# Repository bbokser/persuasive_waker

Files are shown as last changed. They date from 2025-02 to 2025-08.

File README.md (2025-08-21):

# persuasive_waker

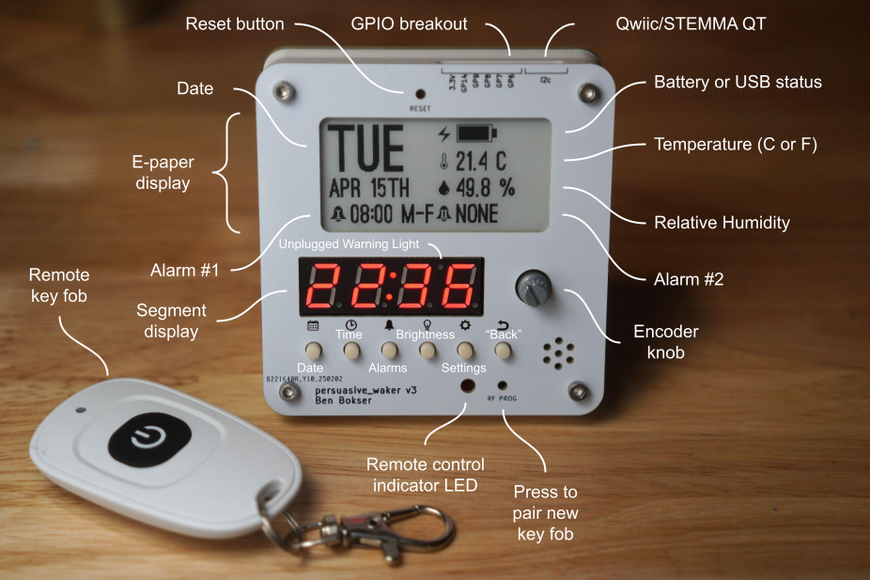
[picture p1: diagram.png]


Persuasive Waker is an open source hardware alarm clock that can't be snoozed or turned off. The alarm is deactivated via a remote key fob, which should be placed as far from the user's bed as possible. E.g. in the bathroom.

The KiCad design files are located in the [`hw`](hw) folder.

The STEP assembly is located [here](hw/step/).

If you just want STLs for printing, they're [here](hw/stl).

## BoM
| Item | QTY| Source |
| ---| ---|--|
| Case | 1  | 3D Print |
| Screen Holder | 1  | 3D Print |
| Spacer | 2  | 3D Print |
| M2.5x0.45-12-SHCS-SS304 | 4  | |
| M2.5x0.45-6-SHCS-SS304 | 4  | |
| M2.5x0.45-4-FHS-SS304 | 2 | |
| PRESSNUT-M2.5x0.45-SS304 | 2 | [Mouser](https://mou.sr/3FToM2v)|
| Battery Holder | 1 | [Mouser](https://mou.sr/4lddciV) |
| THRIN-M2.5X0.45-HS-PL-4L3.5D-BR | 8 | [Amazon](https://www.amazon.com/dp/B0DGPL6RWT)|
| E-Paper Display | 1 | [AliExpress](https://www.aliexpress.us/item/2251832627460771.html)|
| Key Fob | 1 | [AliExpress](https://www.aliexpress.us/item/2251832657961546.html) |
| Alarm PCB | 1 | Custom PCBA Order |
| Front Plate | 1 | Custom PCB Order  |
| Rear Plate | 1 | Custom PCB Order  |

## Mechanical Build
1. Print the case, screen holder, and two spacers.
2. Install the heat-set inserts in the case (x8).
3. Insert the PCB from the front.
4. Plug the E-paper display into the FPC connector.
5. Put the screen holder and spacers into position and then fold the display down onto it. Make sure the display is properly nestled in.
6. Holding the display down, put the front cover on.
7. Screw the front cover on with the M2.5x12 screws.
8. Using an arbor press, press the press-fit nuts into the rear cover.
9. Screw the battery holder onto the rear cover using the flat head screws and loctite. Insert AA batteries.
10. Plug the battery holder into the power connector on the back of the PCB.
11. Screw the rear cover on using the M2.5x6 screws.

## Firmware Setup
1. Install CircuitPython on your Pico by following [this](https://learn.adafruit.com/getting-started-with-raspberry-pi-pico-circuitpython/circuitpython) guide.
The last version tested with this device is [9.2.6.](https://adafruit-circuit-python.s3.amazonaws.com/bin/raspberry_pi_pico/en_US/adafruit-circuitpython-raspberry_pi_pico-en_US-9.2.6.uf2)

2. Install [circup](https://learn.adafruit.com/keep-your-circuitpython-libraries-on-devices-up-to-date-with-circup/prepare) on your computer.

3. Run the following commands to install all necessary libraries.

    ```
    circup bundle-add adafruit/circuitpython-fonts
    circup install adafruit_sht4x adafruit_ssd1680 adafruit_display_text adafruit_ds3231 adafruit_datetime adafruit_display_shapes font_ostrich_sans_black_24 font_ostrich_sans_black_60
    ```
4. Delete `code.py` from the Pico's storage.

5. Clone this repo onto your computer and copy+paste everything in the `src` folder to the Pico's storage.

6. The alarm clock should be functioning now.

## User Manual
See [here](user_manual.md).

### Upgrading from v3.0 to v3.1
1. Replace the old `src` files with the new ones on the `v3.1` branch.
2. Install [circup](https://learn.adafruit.com/keep-your-circuitpython-libraries-on-devices-up-to-date-with-circup/prepare) and run the following.
    ```
    circup bundle-add adafruit/circuitpython-fonts
    circup uninstall font_ostrich_sans_black_30 font_ostrich_sans_black_72
    circup install font_ostrich_sans_black_24 font_ostrich_sans_black_60
    circup update
    ```
    
    Alternatively, you can download the [requirements.txt](requirements.txt) and run the following:
    
    ```
    circup install -r /path/to/requirements.txt
    ```

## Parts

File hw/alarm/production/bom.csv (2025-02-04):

Designator | Footprint | Quantity | Value | LCSC Part #
C1, C18, C3, C6 | 603 | 4 | 4.7uF | C8032
C10, C11, C12, C13, C14, C15, C16, C17, C2, C4, C5, C7, C8, C9 | 603 | 14 | 1uF | C105524
D1, D2, D3, D4 | D_SOD-123 | 4 | MBR0530 | C77336
IC1 | SHT40BD1BR2 | 1 | SHT40-BD1B-R2 | C7461849
IC2 | MAX31328NELB | 1 | MAX31328NELB+ | C3303818
IC3 | PEC11S929KS0015 | 1 | PEC11S-929K-S0015 | C5362681
J1 | FFC2B3524T | 1 | FFC2B35-24-T | C5641278
J3 | M207920642R | 1 | M20-7920642R | C19188561
J4 | SM04BSRSSTBLFSNP | 1 | SM04B-SRSS-TB_LF__SN__P_ | C160404
L1 | INDM3225X240N | 1 | 68 uH | C1499398
LED1 | WP424IDT | 1 | WP424IDT | C5878956
LS1 | CSSI4B20SMTTR | 1 | CSS-I4B20-SMT-TR | C7116026
Q1 | SOT65P210X110-3N | 1 | Si1308EDL-T1-GE3 | C469327
Q2, Q3 | SOT96P240X115-3N | 2 | DMG2305UX-7 | C150470
Q4 | 2SC5585TL | 1 | 2SC5585TL | C337983
R1, R10, R11, R3, R4, R5, R7, R8, R9 | 603 | 9 | 10kΩ | C15401
R12 | 603 | 1 | 14kΩ | C137795
R13 | 603 | 1 | 1kΩ | C103198
R14 | 603 | 1 | 47Ω | C1211
R15, R16 | 603 | 2 | 130Ω | C22796
R2 | 603 | 1 | 0.47Ω | C23411
R6 | 603 | 1 | 180Ω | C100819
S1, S2 | RKB2SJK250SMTRLFS | 2 | RKB2SJK250SMTR_LFS | C2927789
S3, S4, S5, S7, S8, S9 | TL3301BF260QJ | 6 | TL3301BF260QJ | C2886846
U3 | QSOP-24_3.9x8.7mm_P0.635mm | 1 | AS1115-BSST | C2649434
U4 | TDCG1060M_VIS | 1 | TDCR1060M | C7067210

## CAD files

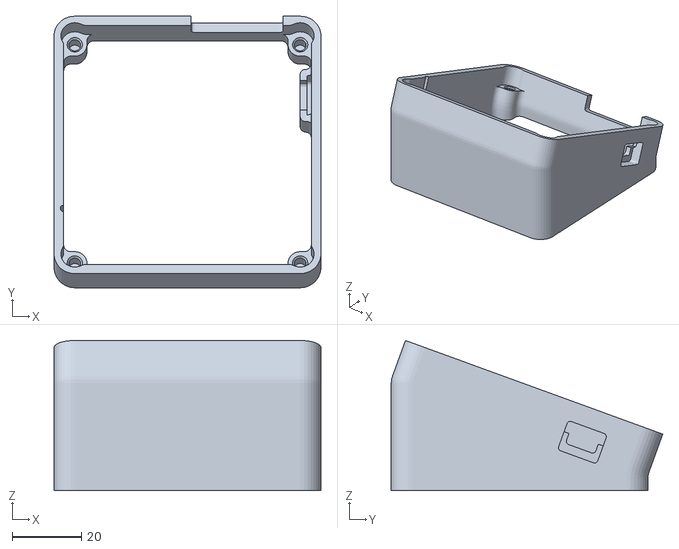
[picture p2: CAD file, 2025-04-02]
hw/stl/CASE V3.STL
77.0 x 78.3 x 43.3

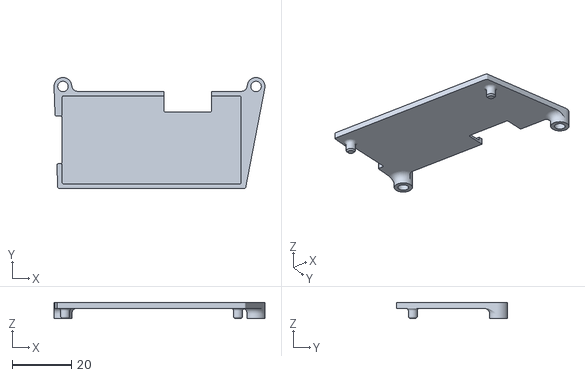
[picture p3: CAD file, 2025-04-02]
hw/stl/SCREEN HOLDER.STL
71.0 x 37.3 x 5.50

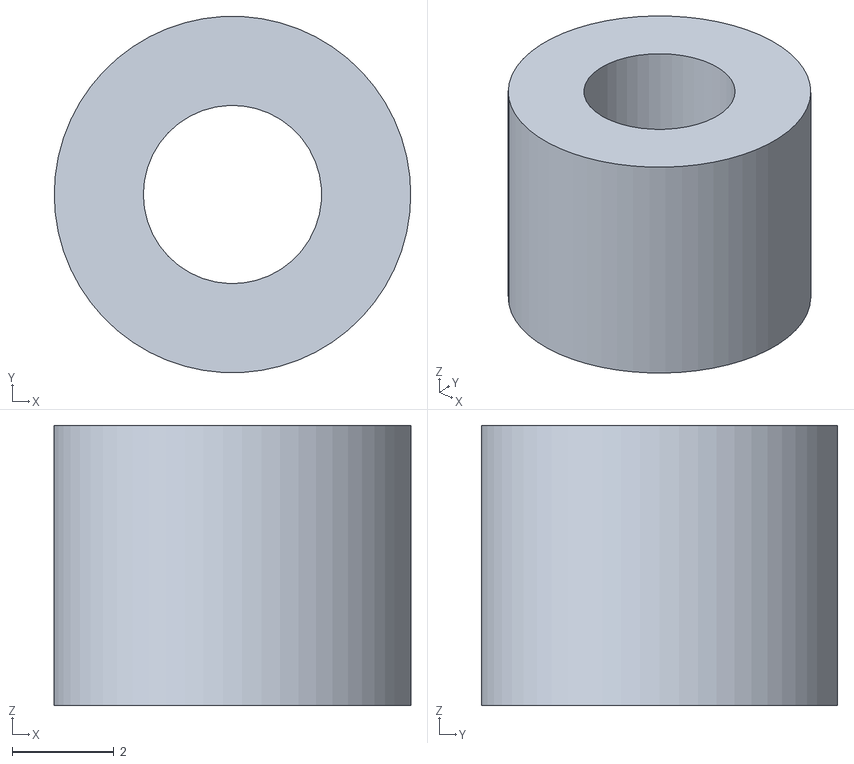
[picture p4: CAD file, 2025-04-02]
hw/stl/SPACER.STL
7.00 x 6.99 x 5.50

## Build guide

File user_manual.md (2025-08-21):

# persuasive_waker: User Manual



## Getting Started
1. Install two AA batteries in the battery compartment.
2. Using the provided screws, screw the back plate onto the case with the batteries on the inner side.
3. Connect the clock to a power source via the USB cable. 
4. Holding down the key fob button, press the date button and select the year by rotating the knob. Press the knob inwards to hit "enter".
5. You will now be asked to enter in the month, followed by the day of the month.
6. Press the time button to set the time of day in a similar manner. 

You can only enter the date, time, and alarm setting mode while simultaneously holding down the key fob button. Otherwise, the device will simply emit an "error" sound effect. This feature is meant to prevent your future self from simply changing the alarm setting (or date/time) a minute before the alarm goes off to avoid getting out of bed.

> [!WARNING]  
> Do not rely on the batteries for power. They will run out fairly quickly. The batteries are for backup power--to prevent pulling the plug from stopping the alarm.

> [!WARNING]  
> Do not attempt to use non-alkaline batteries.

## Using the Alarm
- After setting the alarm hour and time, the display will switch to showing seven flashing lines, which represent the days of the week. You can then choose which days the alarm is set for. The order starts with Monday and ends with Sunday.
- If you wish to cancel your alarm, press the alarm button and then press the "back" button.
- You can enter the second alarm setting mode by pressing the alarm button twice in a row.
- Press the button on the key fob to deactivate the alarm when it sounds. 

I recommend keeping the key fob far away from your bed, probably in the bathroom. But not so far that it's out of range. You should test it before you put it to use--the range will vary depending on your walls.

## Additional Functionalities
### Brightness
- The brightness button will allow you to set the screen brightness.
### Temperature Units
- Hit the option button once to choose your preferred units for temperature.
### Alarm Pitch
- Hit the option button twice to go into the menu for setting the alarm's pitch.
### 24-Hour vs 12-Hour Option
- Hit the option button thrice to go into the menu for selecting between 12-hour mode and 24-hour mode.

## The RESET Button
Try the RESET button if the device seems to be stuck in a bad state. But please notify me if this happens. Or create an [issue](https://github.com/bbokser/persuasive_waker/issues).

> [!NOTE]  
> If you press the RESET button, the E-paper screen will temporarily stop showing the alarm time even though the alarm is still enabled. This is a known issue due to the alarm time being stored in the RTC (clock) chip, not the microprocessor. Transfering this data from the RTC to the microprocessor may require modifications to the [`adafruit_ds3231`](https://docs.circuitpython.org/projects/ds3231/en/latest/api.html#adafruit_ds3231.DS3231.alarm1) library, which I haven't gotten around to. You will have to set the alarm again to make it show.

## Pairing With a New Key Fob
The remote switch receiver is an [RX480E](https://qiachip.com/products/2x-learning-code-receiver-module-for-rf-433mhz-rx-480-e-remote-control-arduino-chip-28131mm-pcb). Use the following instructions to pair a new key fob with your alarm clock (This won't be necessary straight out of the box).

1. Delete existing data by pressing the RF PROG button 8 times. You should see the LED flash 7 times.
2. Learn the new remote by pressing the RF PROG button once. (Note that if you instead press the button twice or thrice in a row, you'll go into other modes, such as toggle mode, which aren't useful for this device. See the link above for more details).
3. The LED should light up, at which point you should press the button on the key fob.
4. You should see the LED flash 3 times. From now on the LED should light up whenever you hit the remote button.

## Updating or Modifying the Software
Modification is as simple as connecting the device to your computer via USB and modifying the .py files.

You can learn more about working with RasPi Pico with CircuitPython [here](https://learn.adafruit.com/getting-started-with-raspberry-pi-pico-circuitpython/circuitpython).

You may encounter a "read-only" error while attempting to save changes. In my experience, this can be fixed by resetting the device.

To update to the latest version, you should follow the firmware setup instructions in the README.

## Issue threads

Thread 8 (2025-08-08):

Qwiic pinout is backward

bbokser, 2025-08-08:
Footprint/schematic is reversed, so the i2c breakout doesn't work out of the box.

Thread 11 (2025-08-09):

RF PROG button doesn't work with legitimate RX480Es

bbokser, 2025-08-09:
Schematic wiring for the RF PROG button is incorrect and needs to be redone. This wasn't caught because it worked with the bootleg versions of the RF board. Should be a pretty simple fix though.

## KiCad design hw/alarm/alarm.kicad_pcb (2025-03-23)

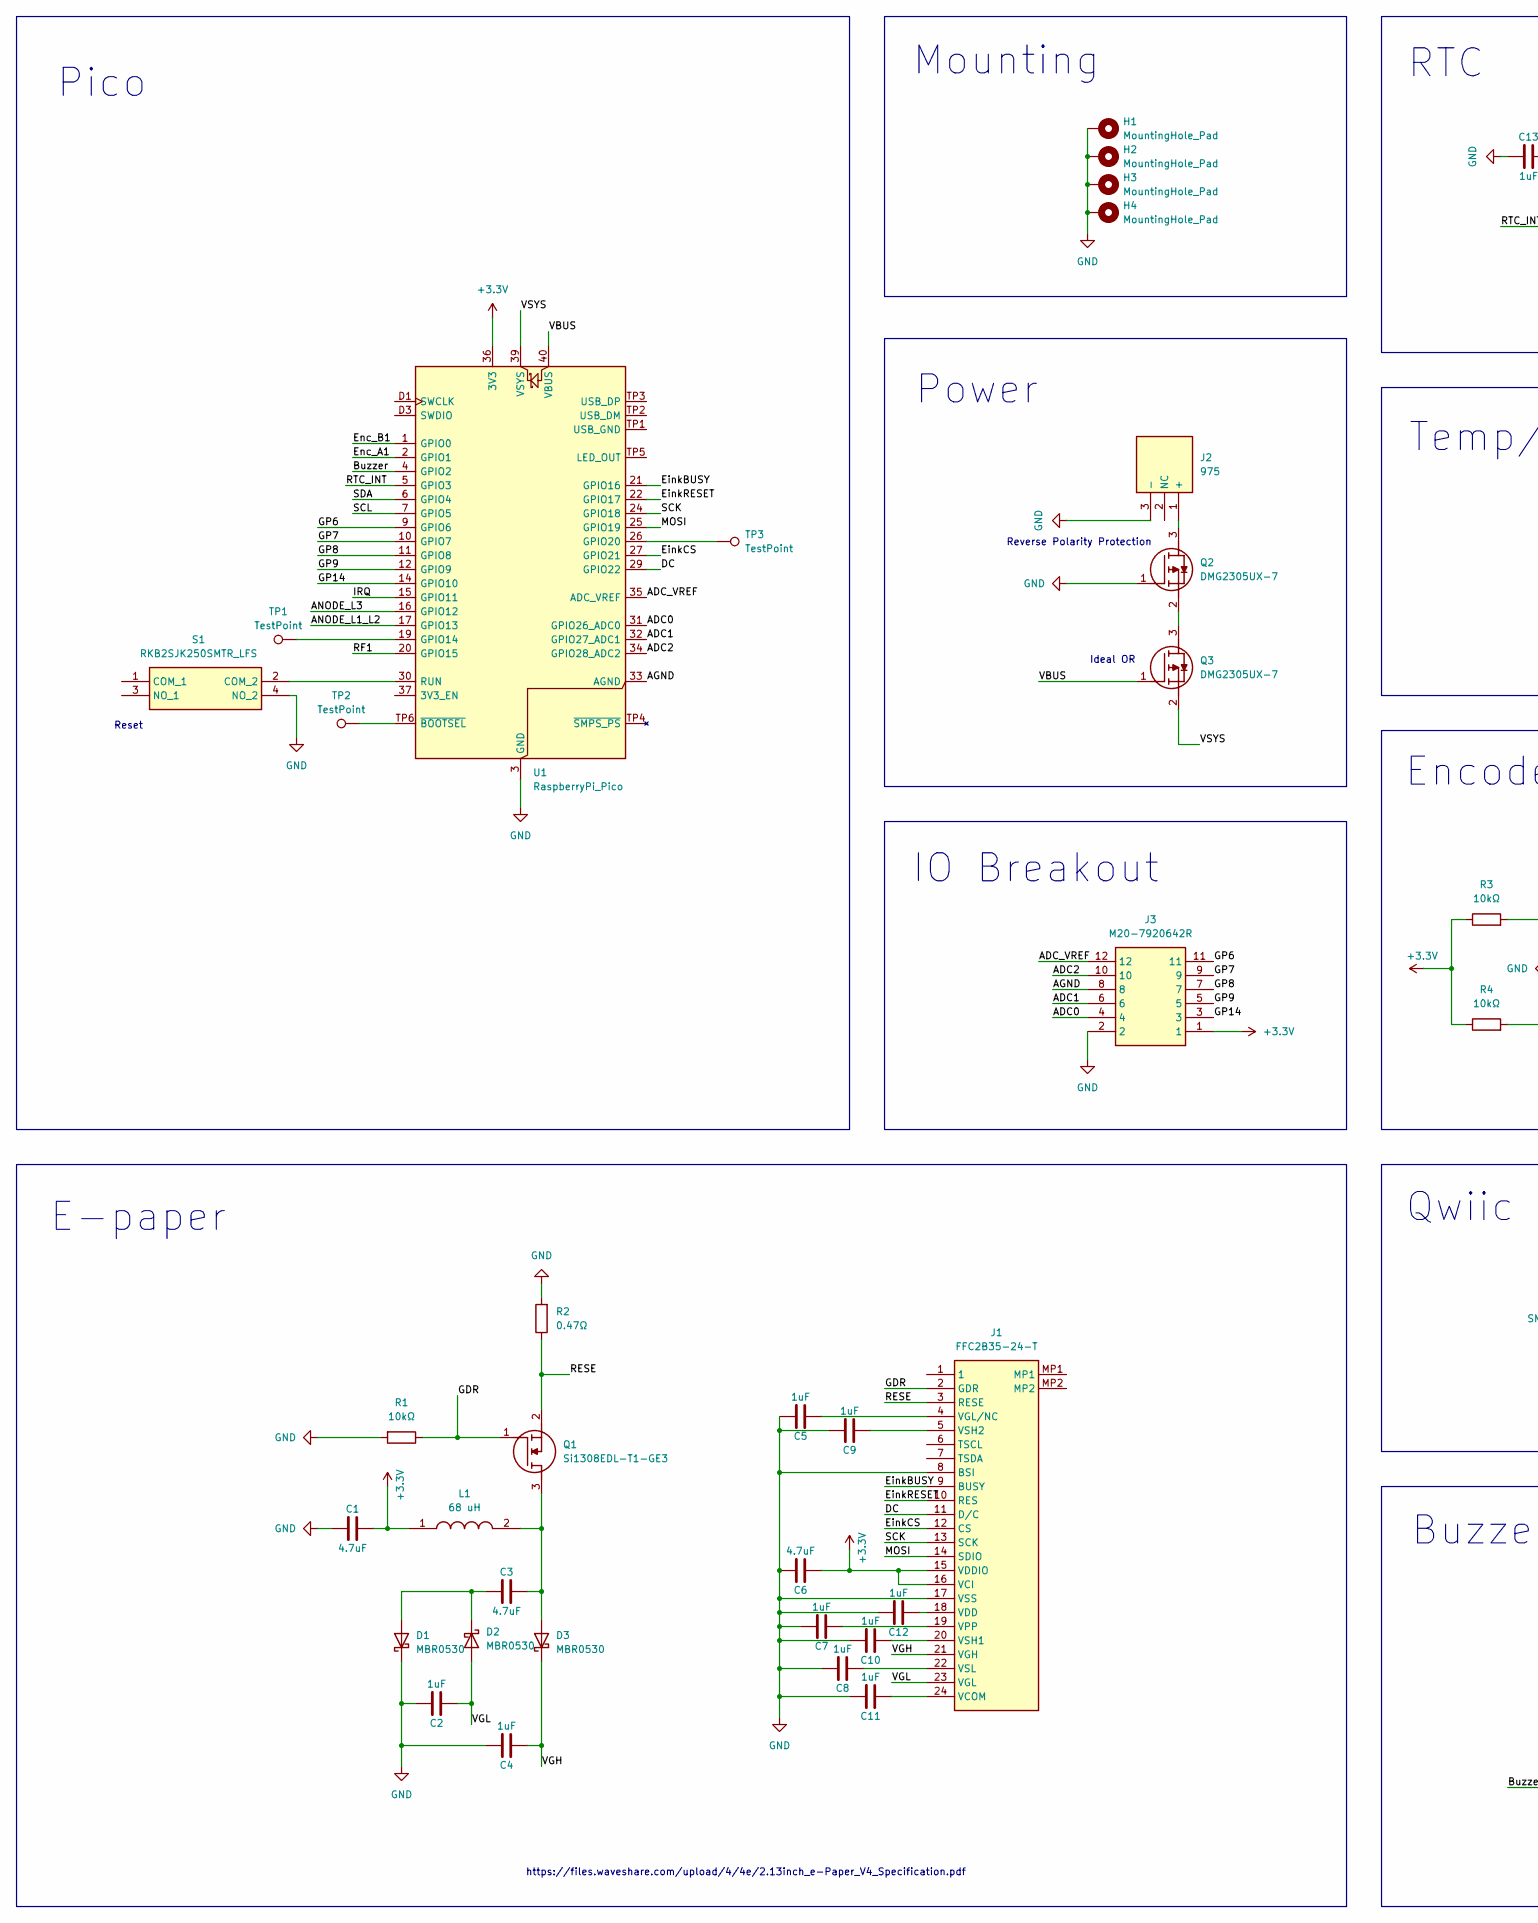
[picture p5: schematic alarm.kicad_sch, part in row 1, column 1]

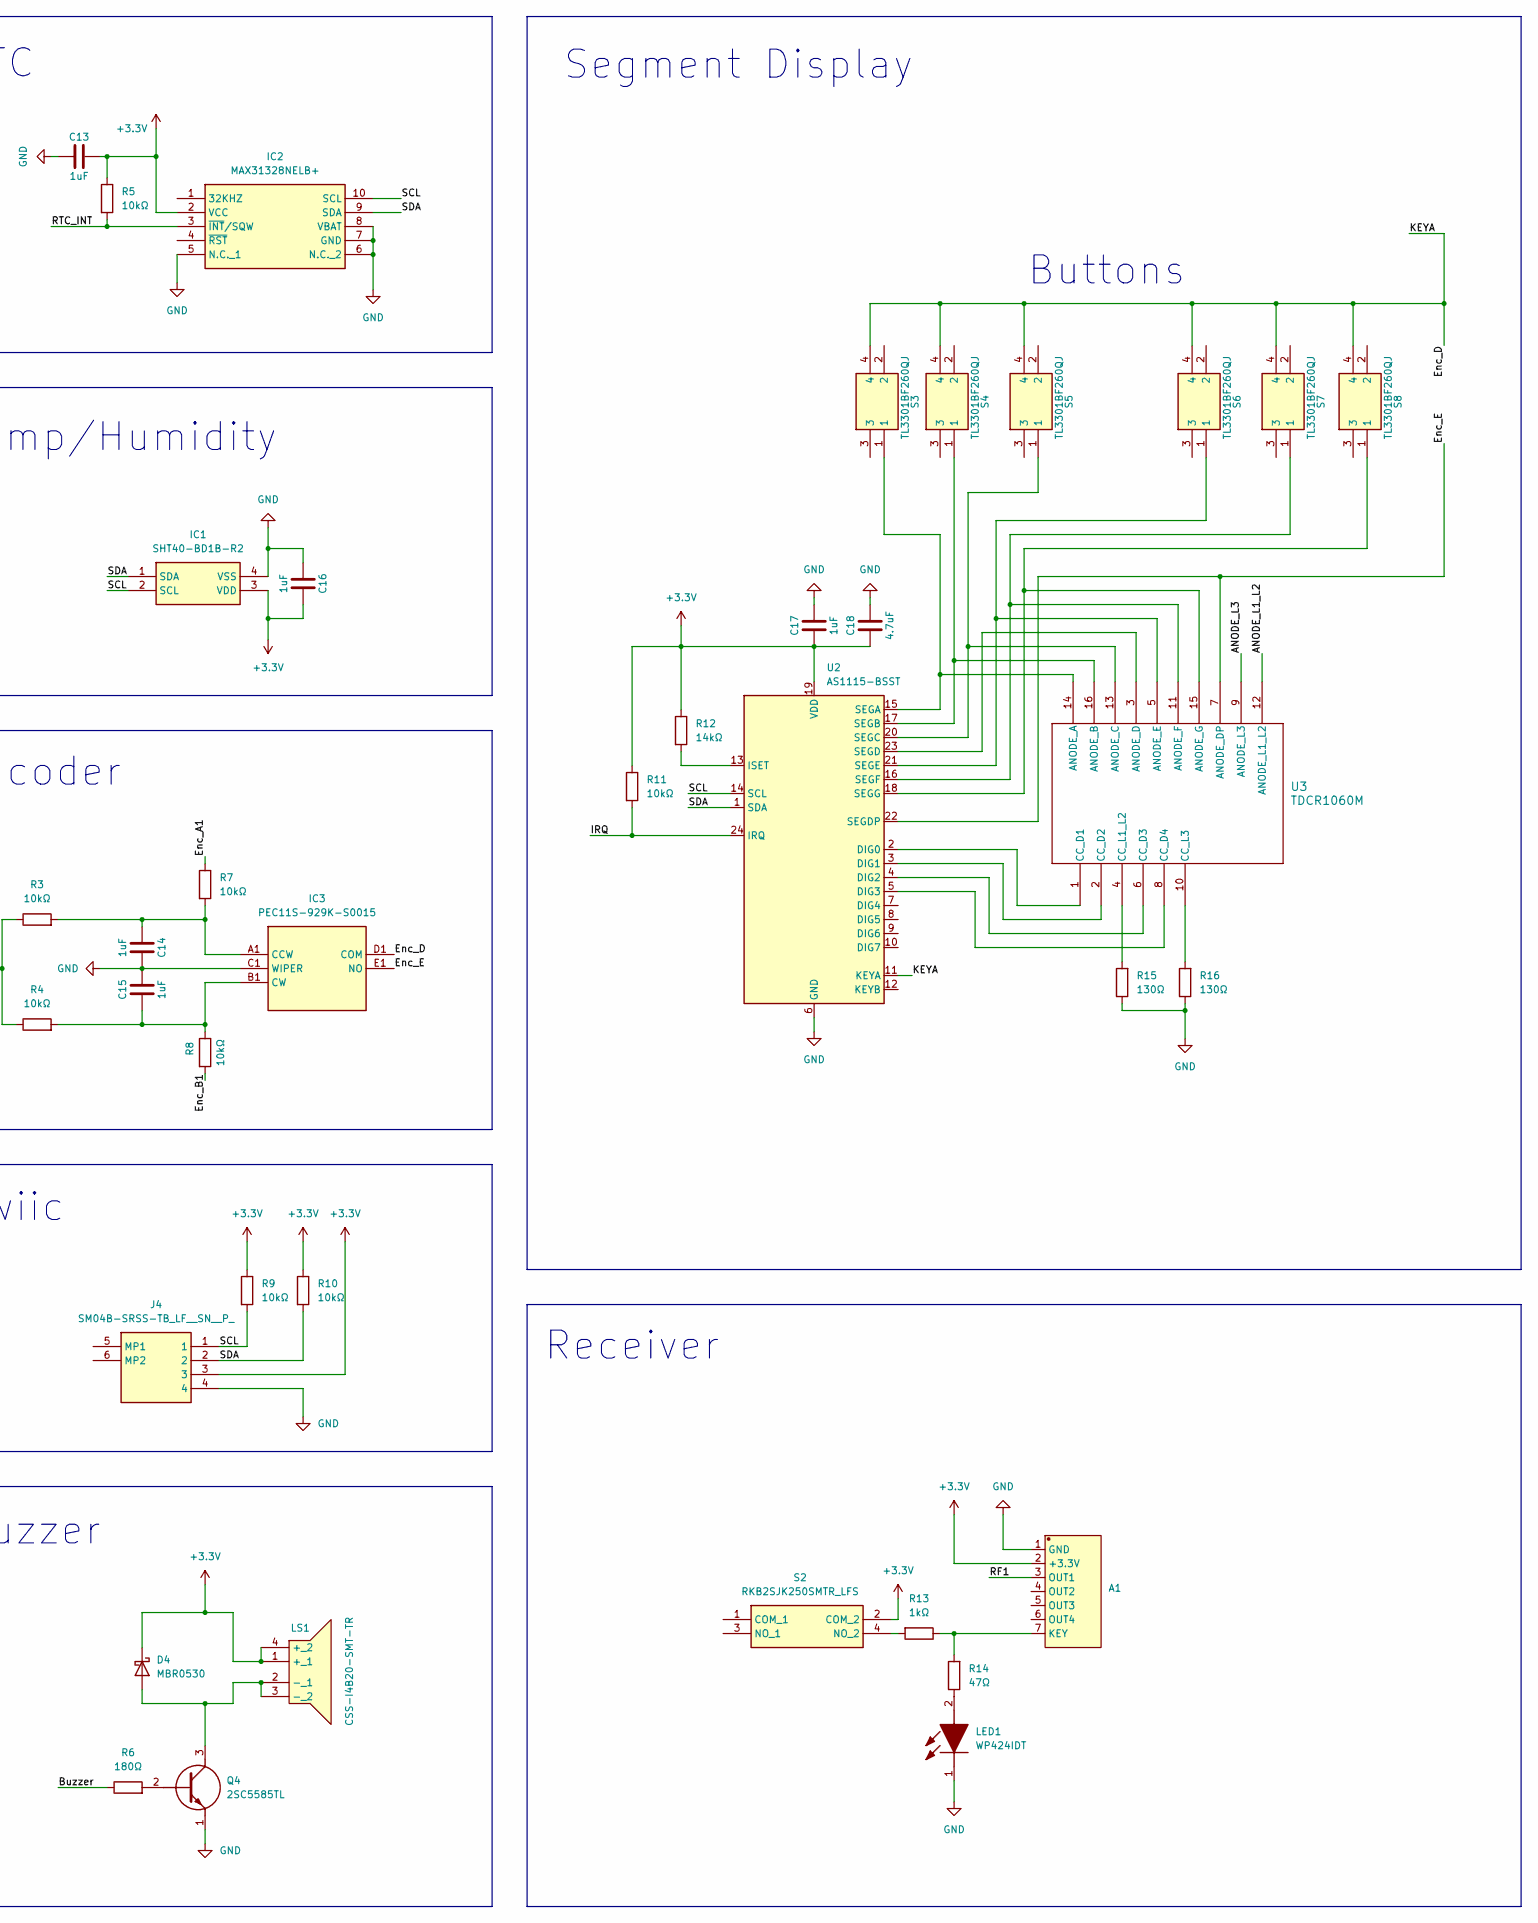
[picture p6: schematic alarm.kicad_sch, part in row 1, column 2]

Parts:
A1: RX480E
C1, C3, C6, C18: 4.7uF; C_0603_1608Metric; LCSC Part # C8032
C2, C4, C5, C7, C8, C9, C10, C11, C12, C13, C14, C15, C16, C17: 1uF; C_0603_1608Metric; LCSC Part # C105524
D1, D2, D3, D4: MBR0530; D_SOD-123; LCSC Part # C77336
H1, H2, H3, H4: MountingHole_Pad; MountingHole_2.7mm_M2.5_DIN965_Pad
IC1: SHT40-BD1B-R2; SHT40BD1BR2; Mouser Part Number 403-SHT40-BD1B-R2
IC2: MAX31328NELB+; MAX31328NELB; Mouser Part Number 700-MAX31328NELB+
IC3: PEC11S-929K-S0015; PEC11S929KS0015; Mouser Part Number 652-PEC11S929K-S0015
J1: FFC2B35-24-T; FFC2B3524T; Mouser Part Number 640-FFC2B35-24-T
J2: 975; Mouser Part Number 534-975
J3: M20-7920642R; M207920642R; Manufacturer_Part_Number M20-7920642R; LCSC Part # C19188561
J4: SM04B-SRSS-TB_LF__SN__P_; SM04BSRSSTBLFSNP; Mouser Part Number 306-SM04BSRSSTBLFSNP
L1: 68 uH; INDM3225X240N; Mouser Part Number 652-CM322522-680KL
LED1: WP424IDT; Mouser Part Number 604-WP424IDT
LS1: CSS-I4B20-SMT-TR; CSSI4B20SMTTR; Mouser Part Number 490-CSS-I4B20-SMT-TR
Q1: Si1308EDL-T1-GE3; SOT65P210X110-3N; Mouser Part Number 78-SI1308EDL-T1-GE3
Q2, Q3: DMG2305UX-7; SOT96P240X115-3N; Mouser Part Number 621-DMG2305UX-7
Q4: 2SC5585TL; Mouser Part Number 755-2SC5585TL
R1, R3, R4, R5, R7, R8, R9, R10, R11: 10kΩ; R_0603_1608Metric_Pad0.98x0.95mm_HandSolder; LCSC Part # C15401
R2: 0.47Ω; R_0603_1608Metric_Pad0.98x0.95mm_HandSolder; LCSC Part # C23411
R6: 180Ω; R_0603_1608Metric_Pad0.98x0.95mm_HandSolder; LCSC Part # C100819
R12: 14kΩ; R_0603_1608Metric_Pad0.98x0.95mm_HandSolder; LCSC Part # C137795
R13: 1kΩ; R_0603_1608Metric_Pad0.98x0.95mm_HandSolder; LCSC Part # C103198
R14: 47Ω; R_0603_1608Metric_Pad0.98x0.95mm_HandSolder; LCSC Part # C1211
R15, R16: 130Ω; R_0603_1608Metric_Pad0.98x0.95mm_HandSolder; LCSC Part # C22796
S1, S2: RKB2SJK250SMTR_LFS; RKB2SJK250SMTRLFS; Mouser Part Number 611-RKB2SJK250SMTRLF
S3, S4, S5, S6, S7, S8: TL3301BF260QJ; Mouser Part Number 612-TL3301BF260QJ
TP1, TP2, TP3: TestPoint; TestPoint_Pad_1.5x1.5mm
U1: RaspberryPi_Pico; RaspberryPi_Pico_Original_SMD
U2: AS1115-BSST; QSOP-24_3.9x8.7mm_P0.635mm; LCSC Part # C2649434
U3: TDCR1060M; TDCG1060M_VIS; LCSC Part # C7067210

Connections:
+3.3V: A1.2 (+3.3V), C1.1, C6.2, C13.1, C16.1, C17.2, C18.2, D4.1 (K), IC1.3 (VDD), IC2.2 (VCC), J1.15 (VDDIO), J1.16 (VCI), J3.1, J4.3, L1.1, LS1.1 (+_1), LS1.4 (+_2), R3.1, R4.1, R5.1, R9.1, R10.1, R11.1, R12.1, S2.2 (COM_2), U1.36 (3V3), U2.19 (VDD)
/ADC0: J3.4, U1.31 (GPIO26_ADC0)
/ADC1: J3.6, U1.32 (GPIO27_ADC1)
/ADC2: J3.10, U1.34 (GPIO28_ADC2)
/ADC_VREF: J3.12, U1.35 (ADC_VREF)
/AGND: J3.8, U1.33 (AGND)
/ANODE_L1_L2: U1.17 (GPIO13), U3.12 (ANODE_L1_L2)
/ANODE_L3: U1.16 (GPIO12), U3.9 (ANODE_L3)
/Buzzer: R6.1, U1.4 (GPIO2)
/DC: J1.11 (D/C), U1.29 (GPIO22)
/EinkBUSY: J1.9 (BUSY), U1.21 (GPIO16)
/EinkCS: J1.12 (CS), U1.27 (GPIO21)
/EinkRESET: J1.10 (RES), U1.22 (GPIO17)
/Enc_A1: R7.1, U1.2 (GPIO1)
/Enc_B1: R8.2, U1.1 (GPIO0)
/Enc_D: IC3.D1 (COM), S3.4, S4.4, S5.4, S6.4, S7.4, S8.4, U2.11 (KEYA)
/Enc_E: IC3.E1 (NO), U2.22 (SEGDP), U3.7 (ANODE_DP)
/GDR: J1.2 (GDR), Q1.1 (G), R1.1
/GP6: J3.11, U1.9 (GPIO6)
/GP7: J3.9, U1.10 (GPIO7)
/GP8: J3.7, U1.11 (GPIO8)
/GP9: J3.5, U1.12 (GPIO9)
/GP14: J3.3, U1.14 (GPIO10)
/IRQ: R11.2, U1.15 (GPIO11), U2.24 (IRQ)
/MOSI: J1.14 (SDIO), U1.25 (GPIO19)
/RESE: J1.3 (RESE), Q1.2 (S), R2.1
/RF1: A1.3 (OUT1), U1.20 (GPIO15)
/RTC_INT: IC2.3 (~INT/SQW), R5.2, U1.5 (GPIO3)
/SCK: J1.13 (SCK), U1.24 (GPIO18)
/SCL: IC1.2 (SCL), IC2.10 (SCL), J4.1, R9.2, U1.7 (GPIO5), U2.14 (SCL)
/SDA: IC1.1 (SDA), IC2.9 (SDA), J4.2, R10.2, U1.6 (GPIO4), U2.1 (SDA)
/VBUS: Q3.1 (G), U1.40 (VBUS)
/VGH: C4.2, D3.1 (K), J1.21 (VGH)
/VGL: C2.2, D2.2 (A), J1.23 (VGL)
/VSYS: Q3.2 (S), U1.39 (VSYS)
GND: A1.1 (GND), C1.2, C2.1, C4.1, C5.1, C6.1, C7.1, C8.1, C9.1, C10.1, C11.1, C12.1, C13.2, C14.1, C15.1, C16.2, C17.1, C18.1, D1.1 (K), H1.1, H2.1, H3.1, H4.1, IC1.4 (VSS), IC2.5 (N.C._1), IC2.6 (N.C._2), IC2.7 (GND), IC2.8 (VBAT), IC3.C1 (WIPER), J1.8 (BSI), J1.17 (VSS), J2.3 (-), J3.2, J4.4, LED1.1 (K), Q2.1 (G), Q4.1 (E), R1.2, R2.2, R15.1, R16.1, S1.4 (NO_2), U1.3 (GND), U1.8 (GND), U1.13 (GND), U1.18 (GND), U1.23 (GND), U1.28 (GND), U1.38 (GND), U1.D2 (GND), U2.6 (GND)
unnamed: A1.7 (KEY), R13.1, R14.2
unnamed: C3.2, D1.2 (A), D2.1 (K)
unnamed: C3.1, D3.2 (A), L1.2, Q1.3 (D)
unnamed: D4.2 (A), LS1.2 (-_1), LS1.3 (-_2), Q4.3 (C)
unnamed: C14.2, IC3.A1 (CCW), R3.2, R7.2
unnamed: C15.2, IC3.B1 (CW), R4.2, R8.1
unnamed: C11.2, J1.24 (VCOM)
unnamed: C12.2, J1.18 (VDD)
unnamed: C5.2, J1.4 (VGL/NC)
unnamed: C7.2, J1.19 (VPP)
unnamed: C10.2, J1.20 (VSH1)
unnamed: C9.2, J1.5 (VSH2)
unnamed: C8.2, J1.22 (VSL)
unnamed: J2.1 (+), Q2.3 (D)
unnamed: LED1.2 (A), R14.1
unnamed: Q2.2 (S), Q3.3 (D)
unnamed: Q4.2 (B), R6.2
unnamed: S1.2 (COM_2), U1.30 (RUN)
unnamed: R13.2, S2.4 (NO_2)
unnamed: TP1.1, U1.19 (GPIO14)
unnamed: TP3.1, U1.26 (GPIO20)
unnamed: TP2.1, U1.TP6 (~BOOTSEL)
unnamed: U2.2 (DIG0), U3.1 (CC_D1)
unnamed: U2.3 (DIG1), U3.2 (CC_D2)
unnamed: U2.4 (DIG2), U3.6 (CC_D3)
unnamed: U2.5 (DIG3), U3.8 (CC_D4)
unnamed: R12.2, U2.13 (ISET)
unnamed: S3.1, U2.15 (SEGA), U3.14 (ANODE_A)
unnamed: S4.1, U2.17 (SEGB), U3.16 (ANODE_B)
unnamed: S5.1, U2.20 (SEGC), U3.13 (ANODE_C)
unnamed: U2.23 (SEGD), U3.3 (ANODE_D)
unnamed: S6.1, U2.21 (SEGE), U3.5 (ANODE_E)
unnamed: S7.1, U2.16 (SEGF), U3.11 (ANODE_F)
unnamed: S8.1, U2.18 (SEGG), U3.15 (ANODE_G)
unnamed: R15.2, U3.4 (CC_L1_L2)
unnamed: R16.2, U3.10 (CC_L3)

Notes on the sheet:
Receiver
IO Breakout
Power
https://files.waveshare.com/upload/4/4e/2.13inch_e-Paper_V4_Specification.pdf
Mounting
Ideal OR
Buttons
RTC
Segment Display
Buzzer
Encoder
Temp/Humidity
Qwiic
E-paper
Pico
Reset
Reverse Polarity Protection

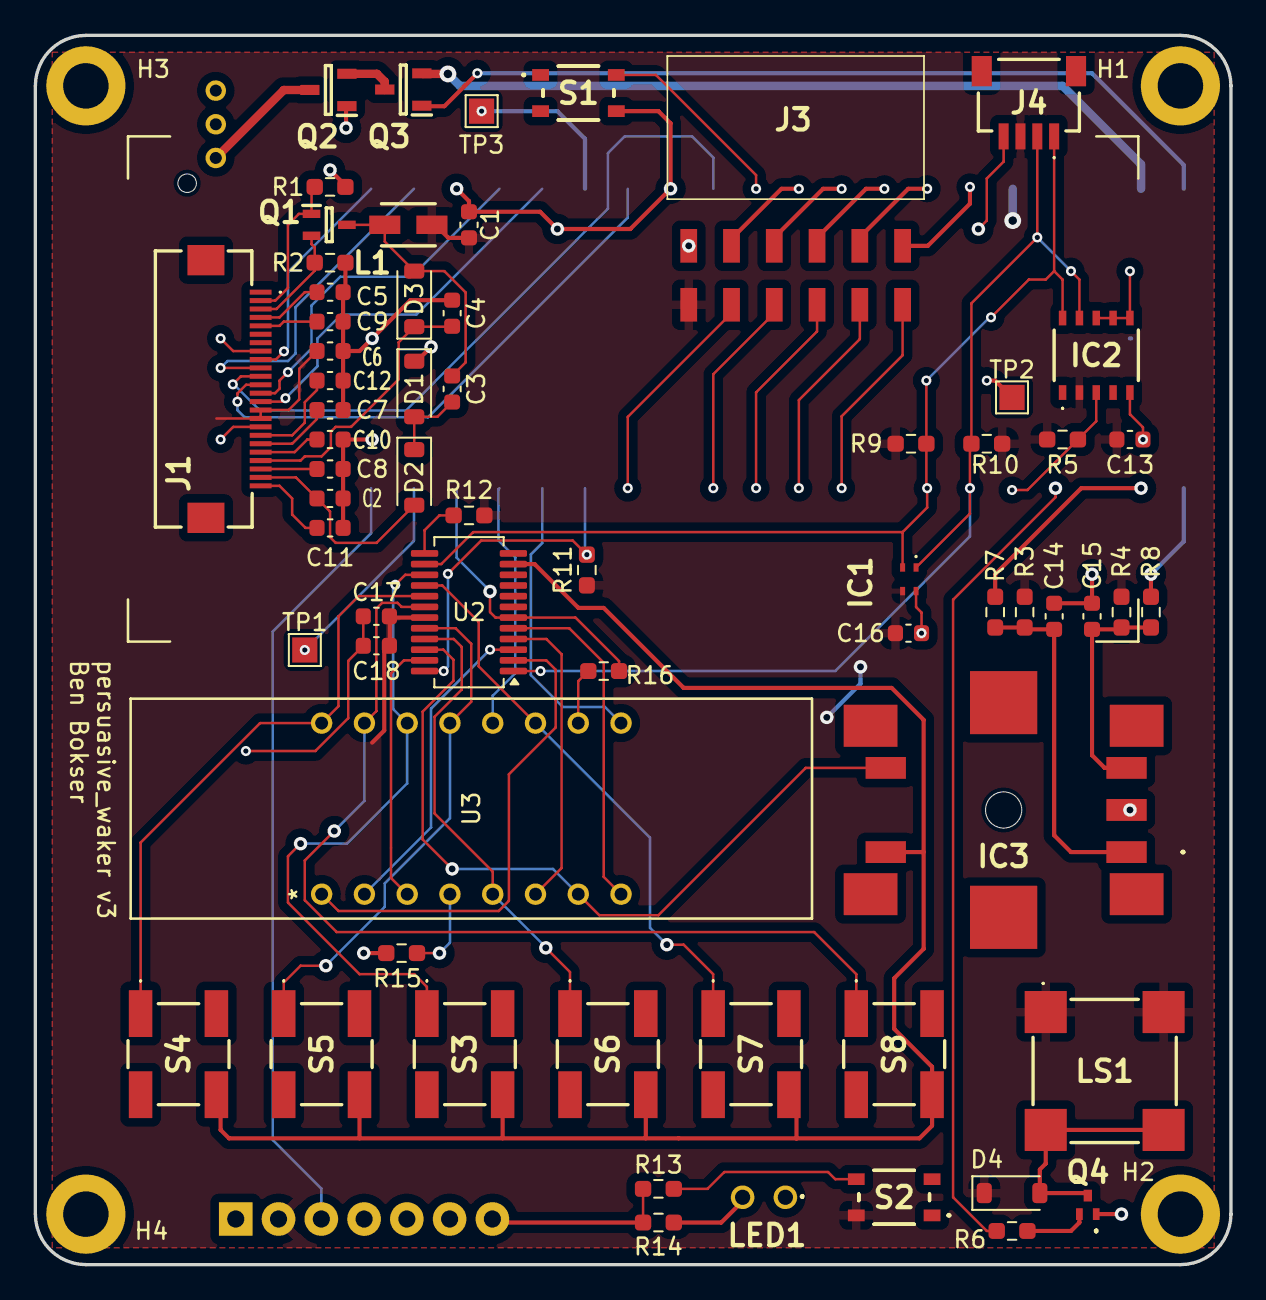
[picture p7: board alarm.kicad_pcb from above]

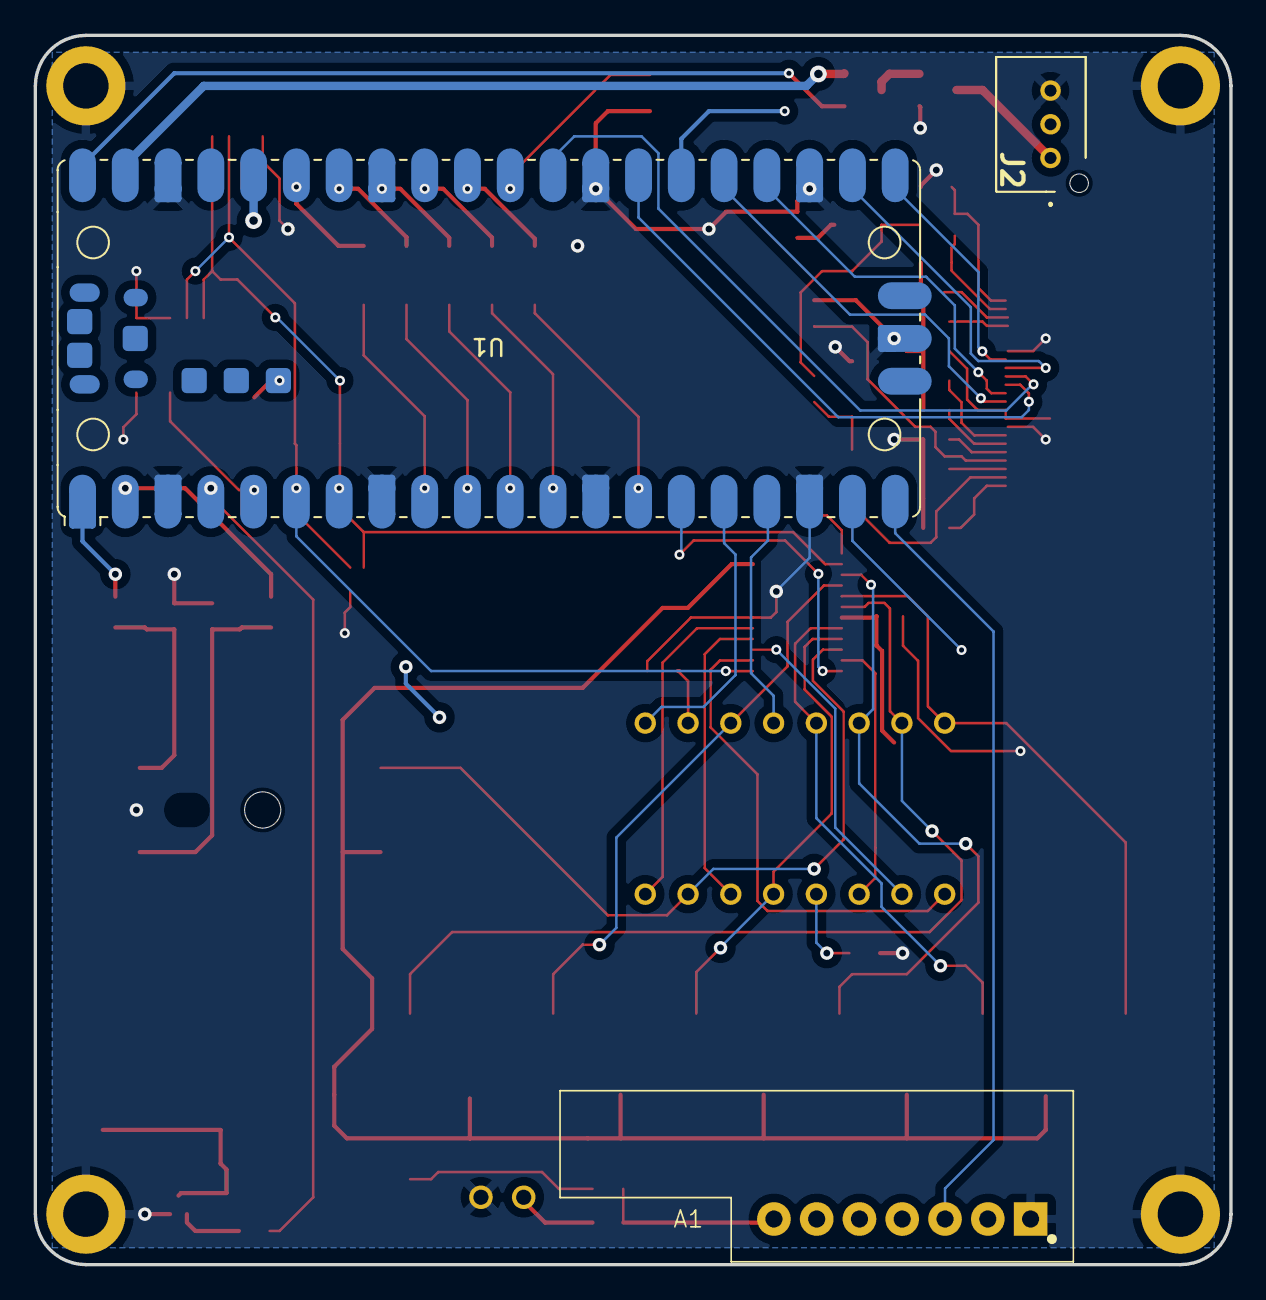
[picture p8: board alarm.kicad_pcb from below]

Board: 2 copper layers, 71.0 x 73.0 mm, 71 parts (3 on the bottom side), 72 nets.

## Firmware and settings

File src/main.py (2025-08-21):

import time
import board
import busio

from fsm import FSM

# hardware
from batt import Batt
from inkdisp import InkDisp
from clock import Clock
from as1115 import AS1115
from encoder import Encoder
from buzzer import Buzzer
from button import PinButton, ScanButton
from sense_ht import HTSensor
from led import LED

# time.sleep(5)  # to ensure serial connection does not fail


class OS(FSM):
    def __init__(self, verbose):
        # initialize class objects
        brightness_init = 2
        i2c = busio.I2C(scl=board.GP5, sda=board.GP4)
        self.as1115 = AS1115(i2c, brightness=brightness_init)
        self.clock = Clock(i2c)
        # this has to run after clock is created
        super().__init__(verbose=verbose)
        # disable the alarms on reset because I haven't figured out how to retrieve the saved info from the rtc
        # self.clock.alarm1.disable()
        # self.clock.alarm2.disable()
        self.rf = PinButton(board.GP15)
        self.enc_button = ScanButton()
        self.alarm_button = ScanButton()
        self.opt_button = ScanButton()
        self.battery = Batt(pin_vbatt=board.VOLTAGE_MONITOR, pin_usb=board.VBUS_SENSE)
        self.encoder = Encoder(pinA=board.GP1, pinB=board.GP0)
        self.buzzer = Buzzer(board.GP2)
        self.sensor = HTSensor(i2c, address=0x45, units=0)
        # segment display colon
        self.seg_colon = LED(board.GP13, brightness_init / 15)
        self.seg_colon.on()
        # segment display apostrophe
        self.seg_apost = LED(board.GP12, brightness_init / 15)

        self.inkdisp = InkDisp(cs=board.GP21, dc=board.GP22, reset=board.GP17)
        self.update_disp()

        # 24 vs 12 hour format
        self.format = 0
        self.format_new = 0

        self.wday_idx = 0
        self.wday_set_new = [0] * 7
        self.dt = 0.1
        self.beat_rate = 0.3  # should be a multiple of dt

    def run(self):
        z = 0
        k = 0
        self.heartbeat = True
        k_beat = int(self.beat_rate / self.dt)

        j = 0
        # how many seconds before refresh
        refresh_time = 10 * 60
        refresh_counter = int(refresh_time / self.dt)
        # reheat the sensor chip once per day
        reheat_counter = int(24 * 60 * 60 / refresh_time)
        self.power_value_prev = self.battery.usb_power.value

        while True:
            if k >= k_beat:
                k = 0
                self.heartbeat = not self.heartbeat

            # buttons register-physical-symbol order
            # 5-S4-date, 4-S5-time, 6-S3-alarm, 3-S6-light, 1-S7-gear, 0-S8-back, 7-Enc-Enter
            buttons = self.as1115.scan_keys()
            self.b_back = buttons[0]
            self.b_options = self.opt_button.update(buttons[1])
            self.b_set_brightness = buttons[2]
            self.b_set_time = buttons[4]
            self.b_set_date = buttons[5]
            self.b_set_alarm = self.alarm_button.update(buttons[6])
            self.b_enter = self.enc_button.update(buttons[7])

            self.execute()

            # refresh inkdisp, make sure at least 3 minutes have passed before you refresh again
            if j > refresh_counter:
                if z == 0:
                    self.sensor.set_mode_read()
                j = 0
                self.update_disp()
                z += 1
                if z > reheat_counter:
                    self.sensor.set_mode_heat()
                    z = 0

            power_value = self.battery.usb_power.value
            # warning light for being unplugged
            if power_value is False:
                self.seg_apost.blink(self.heartbeat)

            if self.power_value_prev != power_value:
                self.update_disp()
                if power_value is True:
                    self.seg_apost.off()

            self.power_value_prev = power_value

            k += 1
            j += 1
            time.sleep(self.dt)

    def update_disp(self):
        disp_info = {
            "weekday": self.clock.get_weekday_str(),
            "month": self.clock.get_month_str(),
            "day": self.clock.get_day_str(),
            "year": self.clock.get_year_str(),
            "alarm1": self.clock.alarm1.get_str(),
            "alarm1wdays": self.clock.alarm1.get_wday_set_str(),
            "alarm2": self.clock.alarm2.get_str(),
            "alarm2wdays": self.clock.alarm2.get_wday_set_str(),
            "temp": self.sensor.get_temperature(),
            "humidity": self.sensor.get_humidity(),
            "batt": self.battery.get_batt_frac(),
            "usb": self.battery.usb_power.value,
            "meridiem": self.clock.get_meridiem_str(),
        }
        self.inkdisp.clear()
        self.inkdisp.apply_info(disp_info)
        self.inkdisp.update()


if __name__ == "__main__":
    verbose = True
    os = OS(verbose)
    os.run()

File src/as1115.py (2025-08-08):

from adafruit_bus_device import i2c_device
from adafruit_register import i2c_bit
from adafruit_register import i2c_bits

# from typing import Union, List, Tuple, Optional
from busio import I2C
import time


AS1115_CLEAR = 15  # BCD
AS1115_REGISTER = {
    "DECODE_MODE": 0x09,  # Enables decoding on selected digits
    "GLOBAL_INTENSITY": 0x0A,  # Sets the entire display intensity
    "SCAN_LIMIT": 0x0B,  # Controls how many digits are to be displayed
    "SHUTDOWN": 0x0C,  #
    "SELF_ADDRESSING": 0x2D,  # Uses 2 of the 16 keys to change the device's address
    "FEATURE": 0x0E,  # Enables various features such as clock mode and blinking
    "DISPLAY_TEST_MODE": 0x0F,  # Detects open or shorted LEDs
    "DIG01_INTENSITY": 0x10,  # Sets the display intensity for digit 0 and 1
    "DIG23_INTENSITY": 0x11,  # Sets the display intensity for digit 2 and 3
    "DIG45_INTENSITY": 0x12,  # Sets the display intensity for digit 4 and 5
    "DIG67_INTENSITY": 0x13,  # Sets the display intensity for digit 6 and 7
    "KEY_A": 0x1C,  # Gets the result of the debounced keyscan for KEYA
    "KEY_B": 0x1D,  # Gets the result of the debounced keyscan for KEYB
}

AS1115_SHUTDOWN_MODE = {
    "SHUTDOWN_MODE": 0x00,  #  Shutdown and reset FEATURE register to default settings.
    "NORMAL_OPERATION": 0x01,  #  Resume operation and reset FEATURE register to default settings.
    "RESET_FEATURE": 0x00,  #  FEATURE register is resetted to default settings.
    "PRESERVE_FEATURE": 0x80,  #  FEATURE register is unchanged.
}

AS1115_DECODE_SEL = {
    "CODE_B_DECODING": 0x00,
    "HEX_DECODING": 0x01,
}

AS1115_DISPLAY_TEST_MODE = {
    "DISP_TEST": 0,  #  Optical display test.
    "LED_SHORT": 1,  #  Starts a test for shorted LEDs.
    "LED_OPEN": 2,  #  Starts a test for open LEDs.
    "LED_TEST": 3,  #  Indicates an ongoing open/short LED test.
    "LED_GLOBAL": 4,  #  Indicates that the last open/short LED test has detected an error.
    "RSET_OPEN": 5,  #  Checks if external resistor Rset is open.
    "RSET_SHORT": 6,  #  Checks if external resistor Rset is shorted.
}

AS1115_DIGIT_REGISTER = [0x01, 0x02, 0x03, 0x04, 0x05, 0x06, 0x07, 0x08]
AS1115_LED_DIAG_REG = [0x14, 0x15, 0x16, 0x17, 0x18, 0x19, 0x1A, 0x1B]
NUMBERS = [
    64 | 32 | 16 | 8 | 4 | 2,  # 0
    32 | 16,  # 1
    64 | 32 | 1 | 4 | 8,  # 2
    64 | 32 | 1 | 16 | 8 | 4,
    2 | 1 | 32 | 16,
    64 | 2 | 1 | 16 | 8,
    64 | 2 | 1 | 16 | 8 | 4,
    64 | 32 | 16,
    1 | 2 | 4 | 8 | 16 | 32 | 64,
    64 | 32 | 16 | 1 | 2,
]

# See Table 11.
LETTERS = {
    "A": 2 | 4 | 64 | 32 | 16 | 1,
    "b": 2 | 4 | 8 | 16 | 1,
    "C": 2 | 4 | 64 | 8,
    "d": 4 | 8 | 16 | 32 | 1,
    "E": 2 | 4 | 8 | 64 | 1,
    "F": 2 | 4 | 64 | 1,
    "H": 2 | 4 | 1 | 16 | 32,
    "h": 2 | 4 | 1 | 16,
    "r": 4 | 1,
}


def nth(value: int, idx: int):
    return value // 10**idx % 10


def reversed_nth(value: int, idx: int, n: int):
    # n is the number of digits
    idx_reversed = n - 1 - idx
    return nth(value, idx_reversed)


def check_brightness_value(value: int) -> None:
    if not 0 <= value <= 15:
        raise ValueError("Brightness must be an int in the range: 0 - 15")


class AS1115_REG:
    # enables external clock
    feature_clock_active = i2c_bit.RWBit(
        register_address=AS1115_REGISTER["FEATURE"], bit=0
    )
    # resets all control registers except for feature register
    feature_reset_all = i2c_bit.RWBit(
        register_address=AS1115_REGISTER["FEATURE"], bit=1
    )
    # enable Code-B or HEX decoding for the selected digits
    feature_decode_sel = i2c_bit.RWBit(
        register_address=AS1115_REGISTER["FEATURE"], bit=2
    )
    # enable blinking
    feature_blink_enable = i2c_bit.RWBit(
        register_address=AS1115_REGISTER["FEATURE"], bit=4
    )
    # set blinking frequency
    feature_blink_freq_sel = i2c_bit.RWBit(
        register_address=AS1115_REGISTER["FEATURE"], bit=5
    )
    # sync blinking with LD/CS pin
    feature_blink_sync = i2c_bit.RWBit(
        register_address=AS1115_REGISTER["FEATURE"], bit=6
    )
    # whether to start blinking w/ display turned on or off
    feature_blink_start = i2c_bit.RWBit(
        register_address=AS1115_REGISTER["FEATURE"], bit=7
    )

    #  Optical display test.
    disp_test_visual = i2c_bit.RWBit(
        register_address=AS1115_REGISTER["DISPLAY_TEST_MODE"], bit=0
    )
    #  Starts a test for shorted LEDs.
    disp_test_led_short = i2c_bit.RWBit(
        register_address=AS1115_REGISTER["DISPLAY_TEST_MODE"], bit=1
    )
    #  Starts a test for open LEDs.
    disp_test_led_open = i2c_bit.RWBit(
        register_address=AS1115_REGISTER["DISPLAY_TEST_MODE"], bit=2
    )
    #  Indicates an ongoing open/short LED test.
    disp_test_led_test = i2c_bit.RWBit(
        register_address=AS1115_REGISTER["DISPLAY_TEST_MODE"], bit=3
    )
    #  Indicates that the last open/short LED test has detected an error.
    disp_test_led_global = i2c_bit.RWBit(
        register_address=AS1115_REGISTER["DISPLAY_TEST_MODE"], bit=4
    )
    #  Checks if external resistor Rset is open.
    disp_test_rset_open = i2c_bit.RWBit(
        register_address=AS1115_REGISTER["DISPLAY_TEST_MODE"], bit=5
    )
    #  Checks if external resistor Rset is shorted.
    disp_test_rset_short = i2c_bit.RWBit(
        register_address=AS1115_REGISTER["DISPLAY_TEST_MODE"], bit=6
    )

    global_intensity = i2c_bits.RWBits(
        num_bits=4, register_address=AS1115_REGISTER["GLOBAL_INTENSITY"], lowest_bit=0
    )
    intensity_01 = i2c_bits.RWBits(
        num_bits=8, register_address=AS1115_REGISTER["DIG01_INTENSITY"], lowest_bit=0
    )
    intensity_23 = i2c_bits.RWBits(
        num_bits=8, register_address=AS1115_REGISTER["DIG23_INTENSITY"], lowest_bit=0
    )

    scan_limit = i2c_bits.RWBits(
        num_bits=3, register_address=AS1115_REGISTER["SCAN_LIMIT"], lowest_bit=0
    )
    decode_mode = i2c_bits.RWBits(
        num_bits=4, register_address=AS1115_REGISTER["DECODE_MODE"], lowest_bit=0
    )
    self_addressing = i2c_bit.RWBit(
        register_address=AS1115_REGISTER["SELF_ADDRESSING"], bit=0
    )
    shutdown_mode_unchanged = i2c_bit.RWBit(
        register_address=AS1115_REGISTER["SHUTDOWN"], bit=7
    )  # no reset
    shutdown_mode_normal = i2c_bit.RWBit(
        register_address=AS1115_REGISTER["SHUTDOWN"], bit=0
    )  # normal operation

    digit_0 = i2c_bits.RWBits(
        num_bits=4, register_address=AS1115_DIGIT_REGISTER[0], lowest_bit=0
    )
    digit_1 = i2c_bits.RWBits(
        num_bits=4, register_address=AS1115_DIGIT_REGISTER[1], lowest_bit=0
    )
    digit_2 = i2c_bits.RWBits(
        num_bits=4, register_address=AS1115_DIGIT_REGISTER[2], lowest_bit=0
    )
    digit_3 = i2c_bits.RWBits(
        num_bits=4, register_address=AS1115_DIGIT_REGISTER[3], lowest_bit=0
    )
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

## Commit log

2024-04-09 add missing variables, alarm ring
    [main.py]
2024-05-29 Start hardware design
    [alarm.kicad_pcb, alarm.kicad_sch]
2024-07-15 Reorganize libraries, various updates to schematic
    [alarm.kicad_pcb, alarm.kicad_sch]
2024-07-18 Add segment display circuit
    [alarm.kicad_pcb, alarm.kicad_sch]
2024-07-25 Start board layout
    [alarm.kicad_pcb, alarm.kicad_sch]
2024-07-26 Continue board layout
    [alarm.kicad_pcb, alarm.kicad_sch]
2024-07-26 Finish board layout initial ver
    [alarm.kicad_pcb, alarm.kicad_sch]
2024-07-26 Minor update
    [alarm.kicad_pcb]
2024-07-27 Make DRC-rec'd changes
    [alarm.kicad_pcb, alarm.kicad_sch]
2024-08-11 Add pull-ups to i2c line, fix problems with DS3231 circuit
    [alarm.kicad_pcb, alarm.kicad_sch]
2024-08-30 Fix alarm reset bug, add refresh timer for inkdisp
    [inkdisp.py, main.py]
2024-09-24 Cobbling together AS1115 driver
2024-09-25 Finish first version of AS1115 driver
2024-10-03 Fix various bugs, get time, settings to work with segment display
    [as1115.py, main.py]
2024-10-12 Add battery monitoring and add winking back using digit brightness
2024-10-13 Fix a multitude of bugs
    [as1115.py, inkdisp.py, main.py]
2024-10-13 Make alarming an FSM state, fix further alarm bugs
    [main.py]
2024-10-15 Fix numerous small bugs
    [batt.py, inkdisp.py]
2024-11-04 Finish v2 schematic and begin v2 board layout
    [alarm.kicad_pcb, alarm.kicad_sch]
2024-11-09 Finish most of board layout
    [alarm.kicad_pcb, alarm.kicad_sch]
2024-11-10 Finish board layout pending last checks
    [alarm.kicad_pcb, alarm.kicad_sch]
2024-11-12 Further tweaks & corrections, create production files
    [alarm.kicad_pcb, alarm.kicad_sch, bom.csv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]
2024-11-14 Add connectors for unused pins
    [alarm.kicad_pcb, alarm.kicad_sch]
2024-11-15 Add LCSC PNs, Replace through-hole breakouts with SMD header, reannotate
    [alarm.kicad_pcb, alarm.kicad_sch, bom.csv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]
2024-12-14 Debugging pin changes
2024-12-16 Add SHT40, colon LED, and day of the week calc
2024-12-25 Fix midnight-crossing problem, make inkdisp refresh check more efficient, and other small fixes
    [main.py]
2024-12-30 add sensor heater functionality
2025-01-27 Start work on v3.0
    [alarm.kicad_pcb, alarm.kicad_sch]
2025-01-30 Add front plate
    [alarm.kicad_pcb, alarm.kicad_sch, bom.csv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]
2025-02-02 Add front and rear plate
    [alarm.kicad_pcb, designators.csv, front_plate.kicad_pcb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]
2025-02-18 Fix S3 wiring mistake and update library paths
    [alarm.kicad_pcb, alarm.kicad_sch]
2025-02-27 Small bug fixes, update manual
    [inkdisp.py]
2025-03-01 Fix bugs involving brightness setting and blinking, disable volume ramp-up
    [main.py]
2025-03-01 Fix apost stuck bug
    [main.py]
2025-03-14 Fix battery calc
2025-03-17 Implementing day-of-week alarm option, minor bugs
    [as1115.py, main.py]
2025-03-19 Fix various bugs, add SetUnits and SetPitch
    [as1115.py, inkdisp.py, main.py]
2025-03-23 Minor weekday indexing bug
    [main.py]
2025-04-02 Improve documentation, extend safety handshake feature to time and date buttons, reduce allowable pitch
    [CASE V3.STL, SCREEN HOLDER.STL, SPACER.STL]
2025-04-18 Fix heating bug, update README
    [main.py]
2025-04-18 Update README to include front and rear plates in BoM
2025-05-04 Extend automatic screen update to USB power value
2025-08-08 Fix battery graphic alignment
    [inkdisp.py]
2025-08-10 Fix variable referenced before assignment bug
    [main.py]
2025-08-17 Walk back alarm-disable-on-reset as it may be exploited
    [main.py]
